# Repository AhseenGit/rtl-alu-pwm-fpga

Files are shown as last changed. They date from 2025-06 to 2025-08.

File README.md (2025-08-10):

#  RTL ALU + PWM FPGA Project

This project implements a structured digital system in Verilog RTL, targeting the Intel DE10-Standard FPGA board. The system includes a modular ALU (arithmetic, logic, shifter) and a PWM generator with three operating modes. It supports simulation, synthesis, and real hardware verification using industry-standard tools.

---

##  System Overview

- Modular ISA-driven ALU
- PWM Generator with 3 modes
- Unified control signal interface via `ALUFN[4:0]`
- Real hardware test on DE10-Standard FPGA
- RTL simulation in ModelSim
- SignalTap-based internal debugging

---

## Functional Unit Control (`ALUFN[4:3]`)

The system selects between functional blocks using the high two bits of a 5-bit `ALUFN` control signal:

| ALUFN[4:3] | Selected Unit | Function Description |
|---|---|---|
| `00` | PWM Generator | Generates variable duty-cycle PWM signal |
| `01` | Arithmetic Unit | Add, subtract, increment, negate |
| `10` | Shifter Unit | Logical/rotate left/right shift |
| `11` | Logical Unit | AND, OR, XOR, NOT, NAND |

> 🛠 Only one unit is active at a time. All units share a unified input/output interface through hardware multiplexing.

---

## Module Descriptions

### ALU Subsystem

Split into three functional RTL modules:

- `alu_arithmetic.v` – signed/unsigned math operations
- `alu_logic.v` – basic boolean logic
- `alu_shifter.v` – logical and rotational shift operations

Output is determined based on `ALUFN[4:0]` and visible via LEDs and HEX displays.

---

### PWM Generator

Implements 3 operating modes:

| Mode | Behavior Description |
|---|---|
| Mode 0 | Fixed duty cycle (manual) |
| Mode 1 | Sweep (ramp up/down duty cycle) |
| Mode 2 | Enable-controlled toggling |

> Mode is selected using lower bits of `ALUFN`.

All PWM outputs are observable on LED pins and via SignalTap.

---

## Tools & Hardware Used

| Tool | Purpose |
|---|---|
| **ModelSim** | RTL-level simulation and waveform viewing |
| **Quartus Prime**  | Synthesis, place-and-route, timing analysis |
| **SignalTap II** | Internal FPGA logic probing (live debugging) |
| **DE10-Standard**  | Target hardware for real FPGA deployment |

*Timing reports were generated automatically by Quartus. No manual slack/path optimizations were applied in this phase.*

---

## Simulation & Test Instructions

### Simulation (ModelSim)

1. Open ModelSim
2. Compile testbenches and RTL modules:
   ```bash
   vsim work.top_tb
  
## Team 
Ahseen & Aram

## contact
Feel free to reach out:
Azazmehhus@gmail.com

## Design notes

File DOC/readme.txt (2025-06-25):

#Lab4

#System Top system (top.vhd)
Inputs:
 -Signal X and Y with n bits long.
 - control signal ALUFN with 5 bits long, where the first two bits (from the left) choose the type of operation i.e.'00' for PWM Generator, '01' for arithmetic, '10' for shifting and '11' for logic ('00' will perform nothing).
  The last 3 bits of ALUFN (ALFN[2-4]) will spcify the operation after selecting the Type of the operation.
  -ENA
  -CLK
  -RST
  - Outputs
  - 4 flags: 'C' will rise to 1 if the operation produced a carry, 'Z' will rise if the result is zero, 'N' will rise if the result is negative and 'V' will rise if there overflow.
  - Output of the operation selected by ALUFN with n bits long.
  - PWM signal

## Adder/Subtractor module (AdderSub.vhd)
Will be selected if ALUFN[0:1]='01'. and will be performing 5 operations as follows:

1.Addition X+Y if ALUFN='01000'
2.Substraction Y-X if ALUFN='01001'
3.N(X) -X when ALUFN='01010'
4.Increment Y by 1 when ALUFN='01011'
5.Decrement Y by 1 when ALUFN='01100'

## Shifter Module (Shifter.vhd)
Will be selected if ALUFN[0:1]='10'. and will be performing 2 shifting operations as follows:

1. Shift Y from the right q times by adding zeros from the right when q is the decimal value of the k first bits of X from the left. Will nbe selected if ALUFN='01000'
2. Shift Y from the left q times by adding zeros from the left when q is the decimal value of the k first bits of X from the left. Will nbe selected if ALUFN='01001'

## Logic Module (Logic.vhd)
Will be selected if ALUFN[0:1]='11'. and will be performing 7 logical operations as follows:

1. not(Y) if ALUFN='11000'
2. Y or X if ALUFN='11001'
3. Y and X if ALUFN='11010'
4. Y xor X if ALUFN='11011'
5. Y nor X if ALUFN='11011'
6. Y nand X if ALUFN='11101'
7. Y xnor X if ALUFN='11111'

## Full Adder Module (FA.vhd) 
Perform addition on two single bits inputs and produce carry when needed.  

## Timer (Timer.vhd)
A counter that counts from zero to Y periodically.

## PWM Unit (PWM.vhd)
A unit that generates a PWM signal according to the ALUFN as follows:
 1.When ALUFN="00000" as PWM mode is Set/Reset.
 2.When ALUFN="00001" as PWM mode is Reset/Set.
 3.When ALUFN="00010" as PWM mode is Toggle.

## TopIO_Interface (IO_InterfaceLAB4.vhd)
Digital system with I/O interface for the hardware test case

## Package (aux_package.vhd)
A file that reuses components that needed frequently in the development of new components.

Studunts: Ahseen & Aram
Instructor: Hanan Reboh

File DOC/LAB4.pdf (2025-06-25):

## Preparation Report LAB4

## ADVANCED CPU ARCHITECTURE AND HARDWARE

## ACCELERATORS LAB

361.1.4693

## Aram Khater 314813452

## Ahseen Alazazma 324038132

מטרת המעבדה

במעבדה זו למדנו כיצד להשתמש ביכולותיה של תוכנת Quartus , ובפרט לבצע סינתזה עבור מודלים שפיתחנו

במעבדה 1 עם תוספת של חלק סינכרוני שמייצר אות PWM בשלושה מצבים. את הסינתזה ביצענו על גבי רכיב

.DE10-Standard | כרטיס | באמצעות | Cyclone II, | מסוג | FPGA

סימולצית ModelSim

נראה סימולציה של החלק החדש שפיתחנו, נותנים ערכים קבועים ל “FFF7=”X,”FFFF=”Y ו

00010“=ALUFN כדי לראות אות PWM יציב.

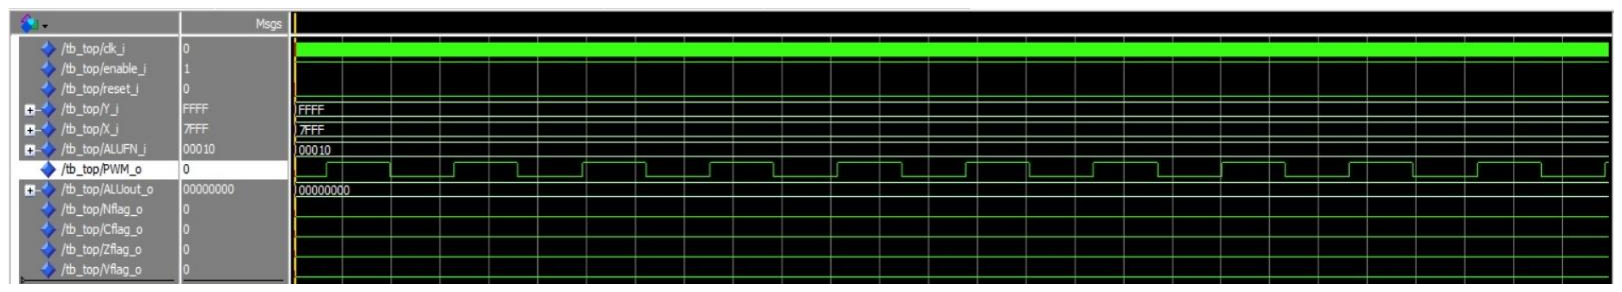
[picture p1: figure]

סימלציה עבור אות PWM במצב Toggle 1:Figure

מציאת תדר מקסימלי

על מנת למצוא את התדר המקסימלי של המערכת, יש להוסיף רגיסטרים סינכרוניים בכניסה וביציאה של ה -ALU.

לשם כך, יצרנו קובץ VHDL חדש אשר עוטף את מערכת ה ALU-ברגיסטרים, כאשר כולם מוזנים מאותו אות שעון.

את תהליך הקימפול והסינתזה ביצענו ללא השמה לפינים, כולל אות השעון, בהתאם להנחיות. לאחר השלמת הקימפול

והסינתזה, תוכנת Quartus מספקת את ערך התדר המקסימלי שבו יכולה המערכת לפעול, והתוצאה שהתקבלה היא:

עבור החלק הקומבינטורי קיבלנו:

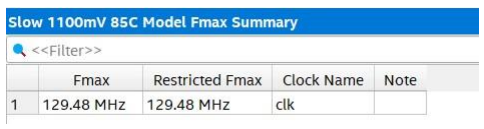
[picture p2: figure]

עבור החלק הסנכרוני קיבלנו:

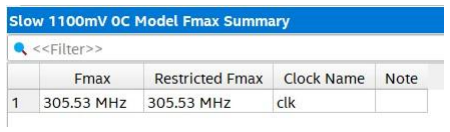
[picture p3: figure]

שיפור תדר השעון באמצעות PLL

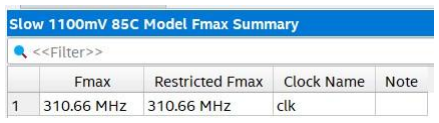
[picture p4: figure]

בנוסף, כפי שלמדנו, ניתן להעלות את תדר השעון של המערכת בעזרת רכיב חומרה מסוג PLL הקיים בכרטיס הפיתוח

שבו אנו משתמשים. רכיב זה מאפשר להכפיל או לשנות את תדר השעון הנכנס בהתאם לצרכי המערכת.

פירוט המערכת

בסעיף זה נציג סקירה כללית של המערכת שפיתחנו, וכן נפרט על תתי-המודולים המרכיבים אותה. עבור כל תת-מודול

נסביר בקצרה את אופן פעולתו, נציג את תרשים ה RTL-שלו לאחר ביצוע הסינתזה, נפרט את הלוגיקה שבה הוא

משתמש, ונאתר את הנתיב הקריטי לפעולתו. את הנתיב הקריטי נציג באמצעות כלים שמספקת תוכנת Quartus.

מערכת ה-ALU

המערכת נועדה לממש מספר מודולים שונים לביצוע פעולות לוגיות ואריתמטיות. כל מודול פועל באופן עצמאי ונפרד

מהאחרים. הבחירה באיזה מודול להשתמש מתבצעת באמצעות אות בחירה הניתן על ידי המשתמש, אשר מפעיל את

המודול הרלוונטי בהתאם לערך שנבחר.

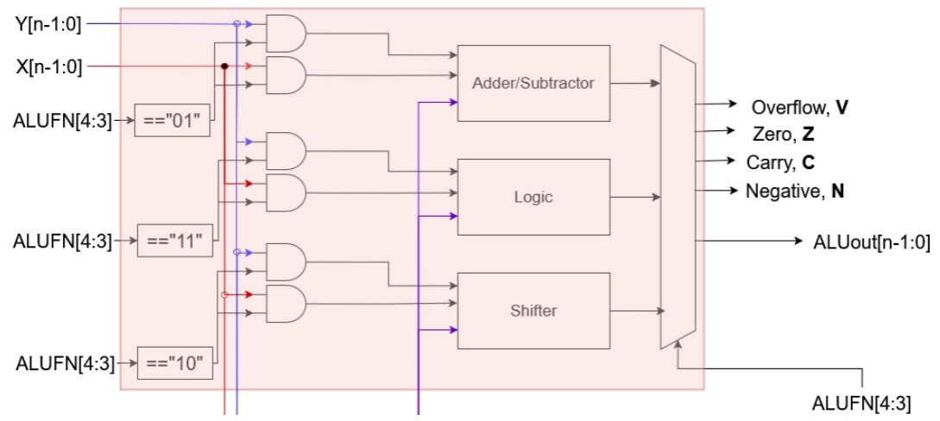
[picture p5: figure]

מודל המערכת 2: Figure

מערכת ה – ALU-מבנה וכניסות/יציאות

בסקירה הבאה נסביר על כל אחד מתתי-המודולים בנפרד. מערכת ה ALU-מקבלת שלוש כניסות עיקריות:

- אות כניסהX
- אות כניסהY
- קו בקרה ,ALUFN שבו:
- הביטים 3ו4- משמשים לבחירת המודול:
- 01 מודול AdderSub
- 10 מודול Shifter
- 11 מודול Logic
- הביטים 0,1,2משמשים כבקרת פעולה פנימית בתוך כל מודול, ומאפשרים לו לפעול במספר אופנים

שונים בהתאם לערכם.

יציאות המערכת כוללות ארבעה רכיבים:

- שלושה דגלים:
o) – Negative (N מסמן אם התוצאה שלילית
o) – Zero (Z מסמן אם התוצאה היא אפס
o) – Carry (C מסמן אם התרחשה נשיאה(Carry(
o) Overflow(V מסמן אם התרחשה גלישה אריתמטית (Overflow (בפעולות חיבור/חיסור
- מוצא – ALUout מייצג את התוצאה של המודול שנבחר לפעולה, בהתאם לערך שבקו הבקרה ALUFN .

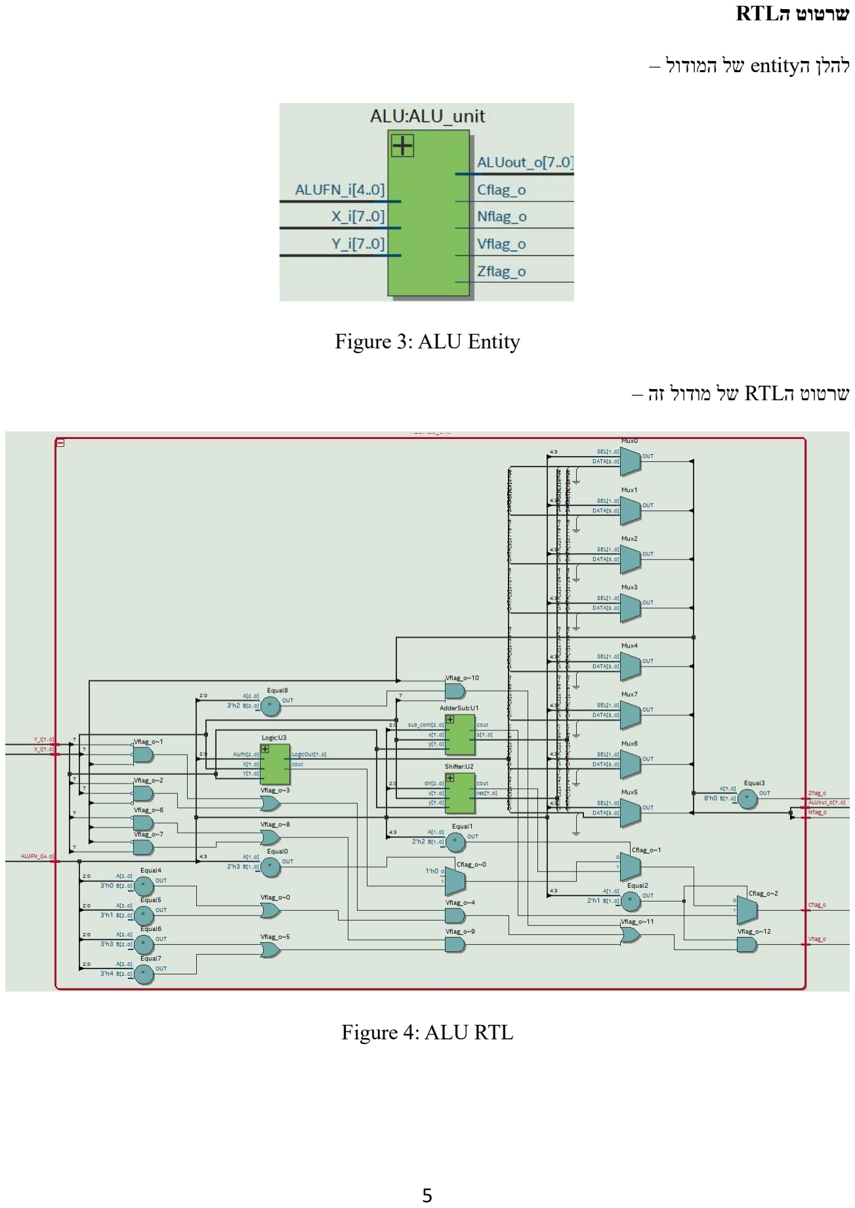
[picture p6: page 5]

שרטוט הRTL

להלן הentity של המודול –

Figure 3: ALU Entity

שרטוט הRTL של מודול זה –

Figure 4: ALU RTL

שימוש בלוגיקה

כידוע, אנו מפתחים קוד לוגי המבוסס על רכיבים לוגיים הניתנים לקונפיגורציה בהתאם לקוד שנכתב – תהליך

שמבוצע כחלק מתהליך הסינתזה. בניתוח זה נציג את הלוגיקה שנעשה בה שימוש עבור כל אחד מהמודולים, בהתאם

לדרישות, ונפרט כיצד ממומשת כל פעולה ברמת השערים או המבנה הפנימי של המודול.

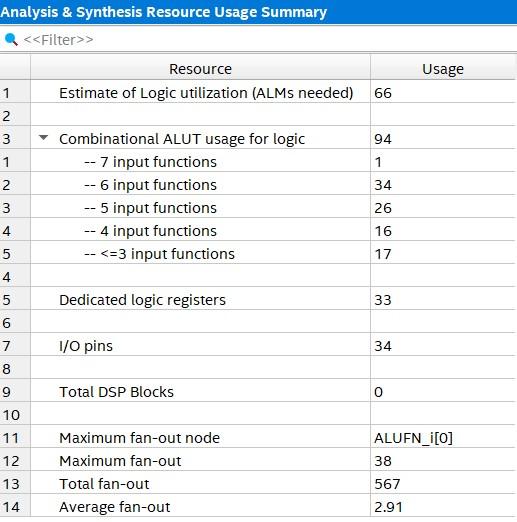
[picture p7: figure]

Figure 5: System Logic Usage

נתיב קריטי

הנתיב הקריטי הוא מרכיב מרכזי להבנת זרימת המידע במערכת, והוא קובע את זמן ההתייצבות המינימלי הדרוש לפני

שניתן לעבד קלט חדש. מאחר שלכל רכיב לוגי קיימת השהיה – גם כאשר הם פועלים במקביל – יש להביא בחשבון

את זמן ההשהיה הכולל במערכת. לכן, איתור הנתיב הקריטי מאפשר לנו להעריך את ביצועי המערכת ולקבוע את

התדר המקסימלי האפשרי לפעולה.

להלן מציאת הנתיב הקריטי עבור מודול זה, כפי שנעשה באמצעות כלי הניתוח של תוכנת Quartus :

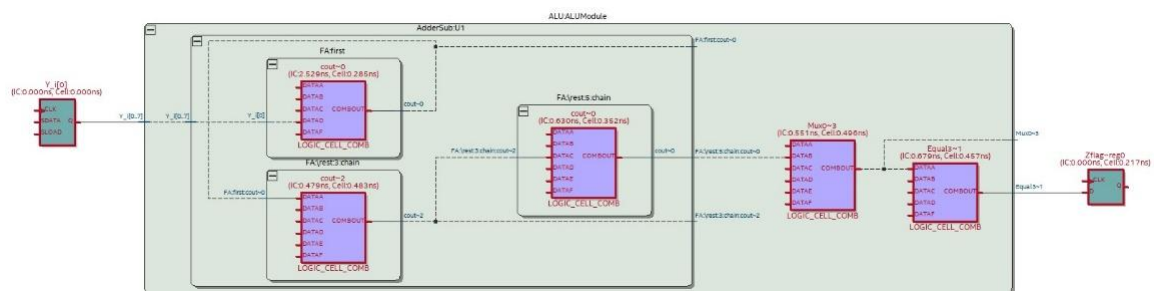
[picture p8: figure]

Figure 6: ALU Critical Path

מודול AdderSub

סקירת פעולת המודול

מודול זה מבצע, בהתאם לקו הבקרה ,ALUFNאחת מתוך מספר פעולות אריתמטיות על שני סיגנלים באורך זהה –

Xו .Y-הפעולות כוללות:

- חיבור (Addition (של X ו Y-באמצעות שרשרת חוסרי חיבור(FA – Adders Full(
- חיסור (Subtraction (באמצעות הוספת המשלים של X
- היפוך ביטים – (NEG (הפעלת היפוך ביט- ביט
- הוספה של 1 ל Y) –Increment (ביצוע 1 + Y
- הפחתה של 1 מ Y) –Decrement (ביצוע 1 – Y
- החלפת סדר בתים ב Y) –Swap (היפוך סדר הבתים של Y

הבחירה בפעולה המתבצעת נעשית לפי הביטים ,[2:0]ALUFN כאשר כל ערך תואם לפעולה שונה.

שרטוט הRTL

להלן הentity של המודול –

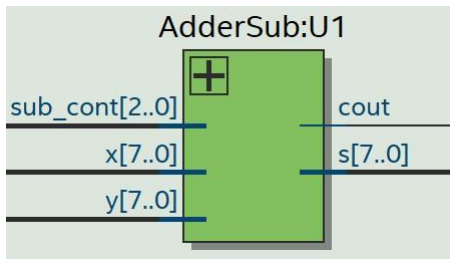
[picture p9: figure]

Figure 7: AdderSub Entity

שרטוט הRTL של מודול זה –

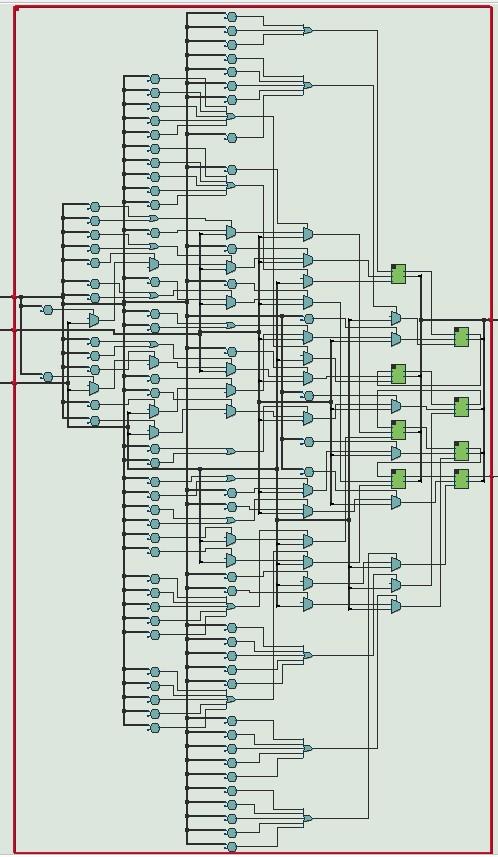
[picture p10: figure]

Figure 8: AdderSub RTL

מודול – Shifter

סקירת פעולת המודול

מודול זה מבצע פעולת הזזה (Shift (על בסיס מבנה ,Shifter Barrel בהתאם לערכי קו הבקרה .ALUFN

כאשר הביטים [2:0]ALUFNהם:

- – '000' מתבצעת הזזה שמאלה
- – '001' מתבצעת הזזה ימינה

למימוש המודול, עברנו על כל אחת מ־ k השכבות כאשר n 2log=k ובכל שכבה מתבצעת הזזה מותנית. עבור כל

שכבה:

- אם הביט המתאים בשכבת הבקרה(ממוצא ה X(הוא 0 – לא מתבצעת הזזה, והמוצא של השכבה זהה

לכניסתה

- אחרת נבצע הזזה בהתאם לשכבה

בנוסף, לצורך חישוב ה Carry-(סיבית שנדחפה החוצה במהלך ההזזה(, יצרנו סיגנל ייעודי אשר שומר את ערכי ה-

Carry בכל שלב, וממנו אנו מחזירים את הסיבית המתאימה )לרוב האחרונה( כמוצא carry של המודול.

שרטוט הRTL

להלן הentity של המודול –

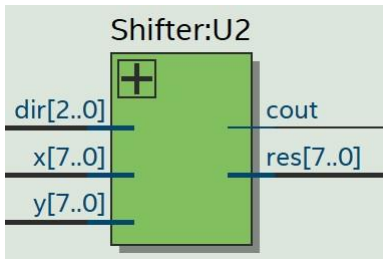
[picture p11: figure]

Figure 9: Shifter Entity

שרטוט הRTL של מודול זה –

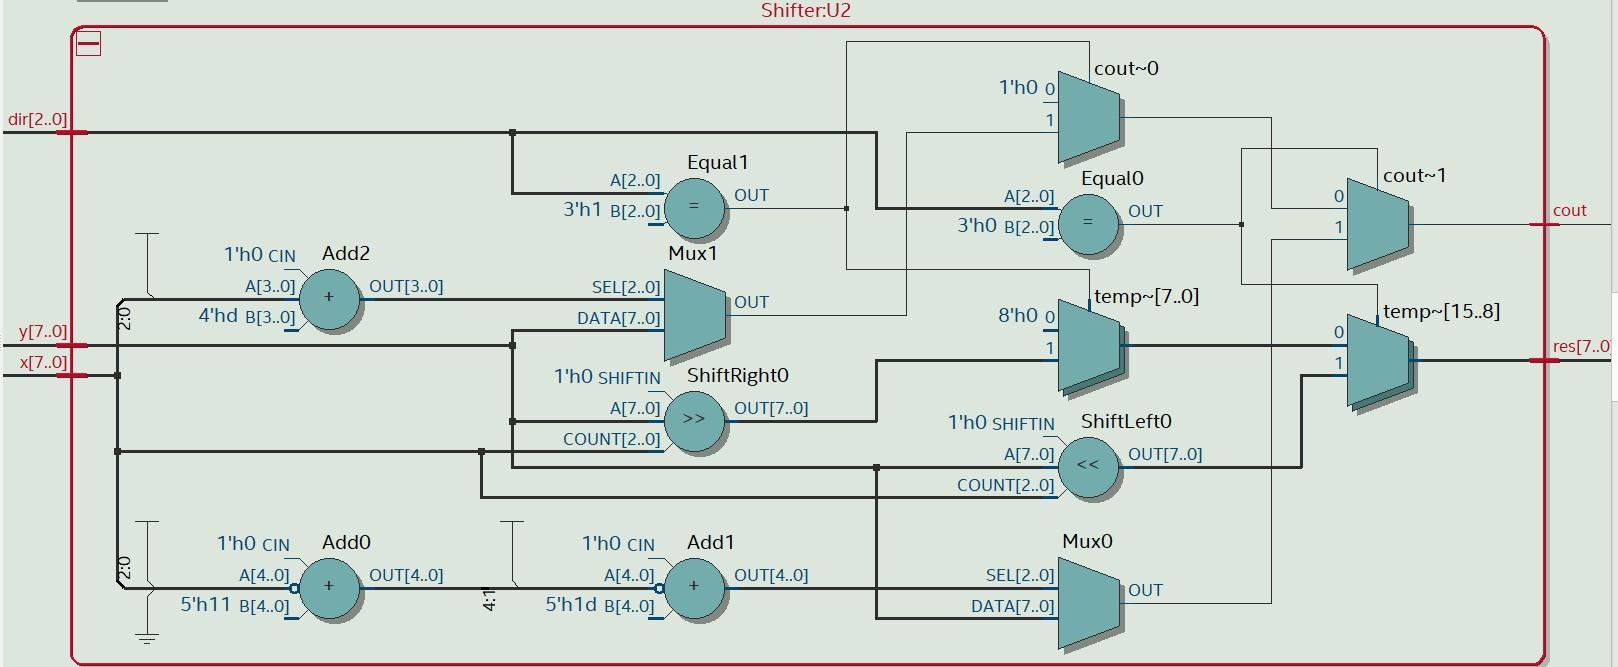
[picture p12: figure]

Figure 10: Shifter RTL

מודול – Logic

סקירת פעולת המודול

מודול זה מבצע פעולות לוגיות שונות בין הסיגנלים Xו ,Y-בהתאם לערכי קו הבקרה ALUFN.

הבחירה בפעולה המתאימה נעשית לפי ערכי הביטים ,[2:0]ALUFNבהתאם להגדרות שניתנו ב ISA-המצורפת.

מבנה המודול מאפשר הרחבה עתידית לפעולות לוגיות נוספות במידת הצורך, תוך שמירה על פשטות המימוש

והיעילות בזמן סינתזה.

שרטוט הRTL

להלן הentity של המודול –

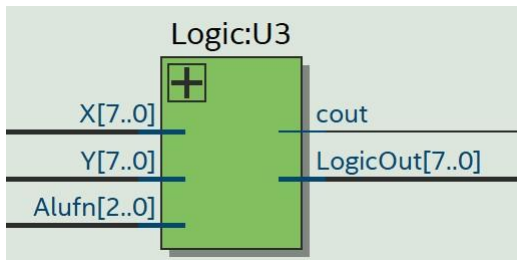
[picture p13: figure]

Figure 11: Logic Entity

שרטוט הRTL של מודול זה –

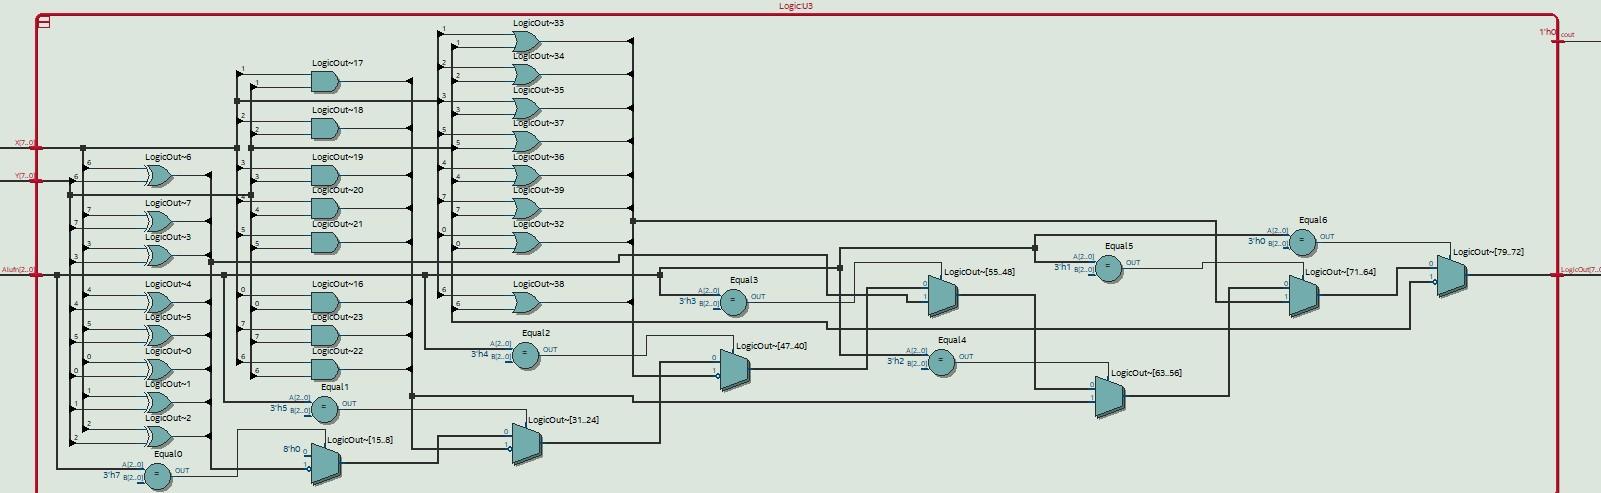
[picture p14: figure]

Figure 12: Logic RTL

מערכת ה PWM

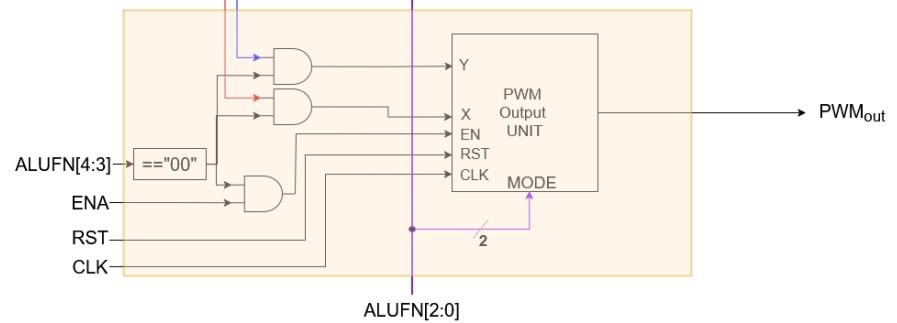
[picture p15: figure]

Figure 13: PWM Module

המערכת תקבל 6 כניסות ותייצר אות PWM בשלושה מצבים:

- אות כניסה X.
- אות כניסה Y.
- שעון CLK.
- קו ENA שעוצר או מפעיל את המערכת.
- קו RST שמאפס את המערכת
- קו בקרה ALUFN כאשר ביטים 0,1 קובעים את המודול הנבחר כך ש-
Set/Reset | במצב | PWM | נבחר | " 00 " | -
Reset/Set | במצב | PWM | נבחר | " 01 " | -
- "10" נבחר PWM במצב Toggle

שרטוט הRTL

להלן הentity של המודול –

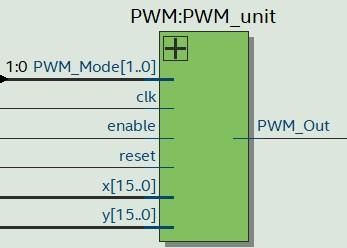
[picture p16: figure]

Figure 14: PWM Entity

שרטוט הRTL של מודול זה –

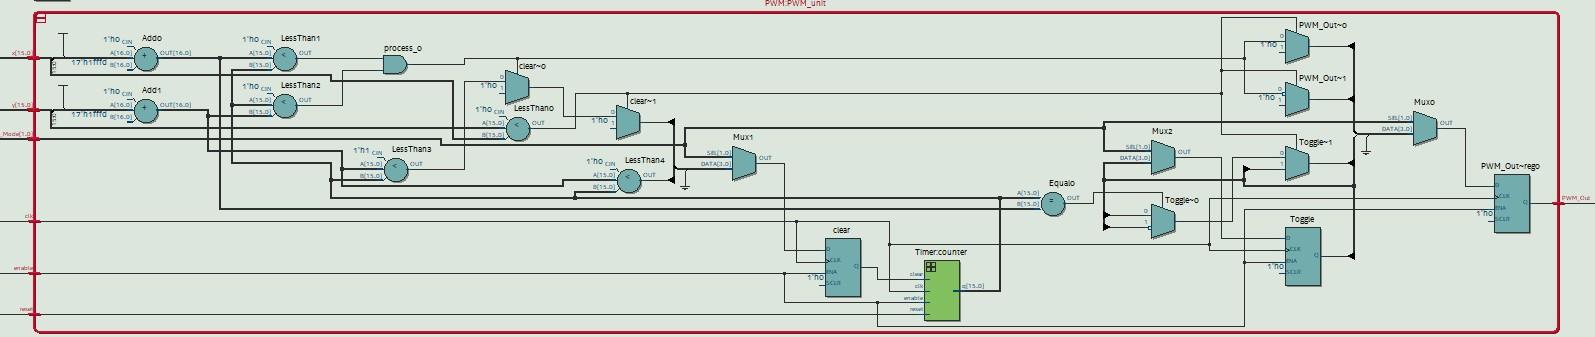
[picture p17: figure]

Figure 15: PWM RTL

בשימוש בלוגיקה

כידוע אנחנו מפתחים קוד לוגי אשר משתמש באלמנטים לוגים שניתן לקנפג אותם בהתאם לקוד, דבר

שנעשה כחלק מתהליך הסינתזה. בניתוח זה נציג את הלוגיה עבור כל מודול כנדרש –

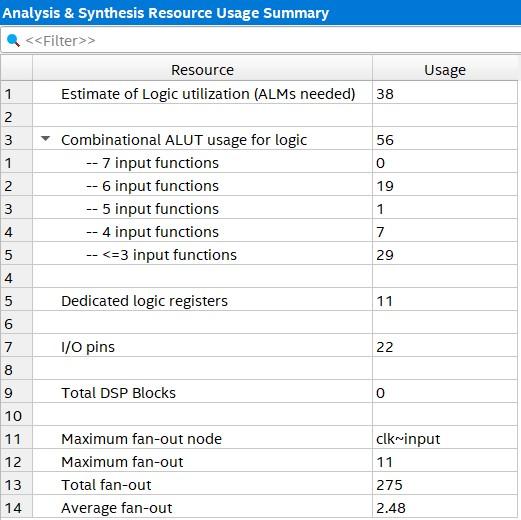
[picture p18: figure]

Figure 16: System Logic Usage

נתיב קריטי

הנתיב הקריטי חשוב ביותר להבנת זרימת המידע במערכת. מפני שלרכיבים יש השהייה גם אם הם

מקביליים אזי עלינו לקחת בחשבון את אורך הזמן שלוקח למערכת להתייצב לפני הכנסת כניסה חדשה.

להלן מציאת הנתיב הקריטי במודול זה –

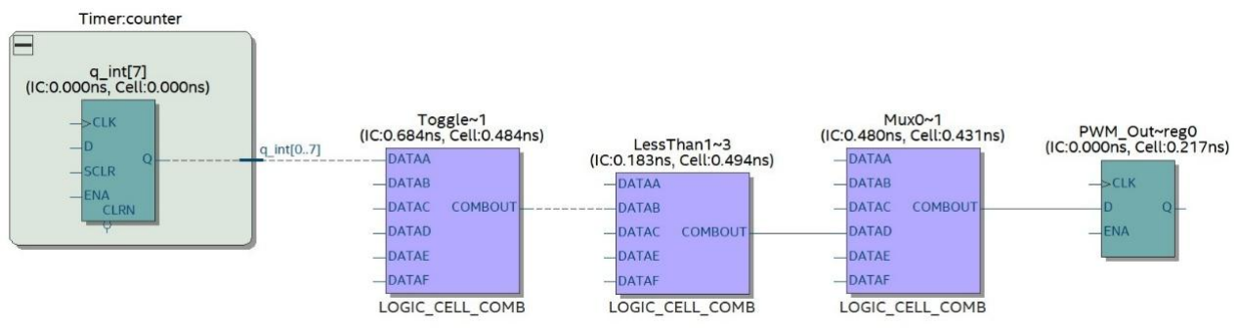
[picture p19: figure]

Figure 17: PWM Unit Critical Path

מודול – Timer

מודול זה מבצע מנייה כלפי מעלה עד שיגיע לערך של Y ומתחיל שוב מנייה מאפס.

שרטוט הRTL

להלן הentity של המודול –

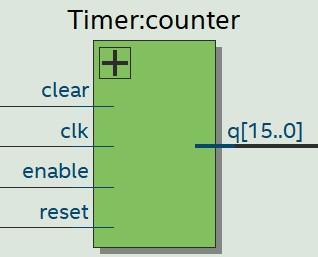
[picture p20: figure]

Figure 18: Timer Entity

שרטוט הRTL של מודול זה –

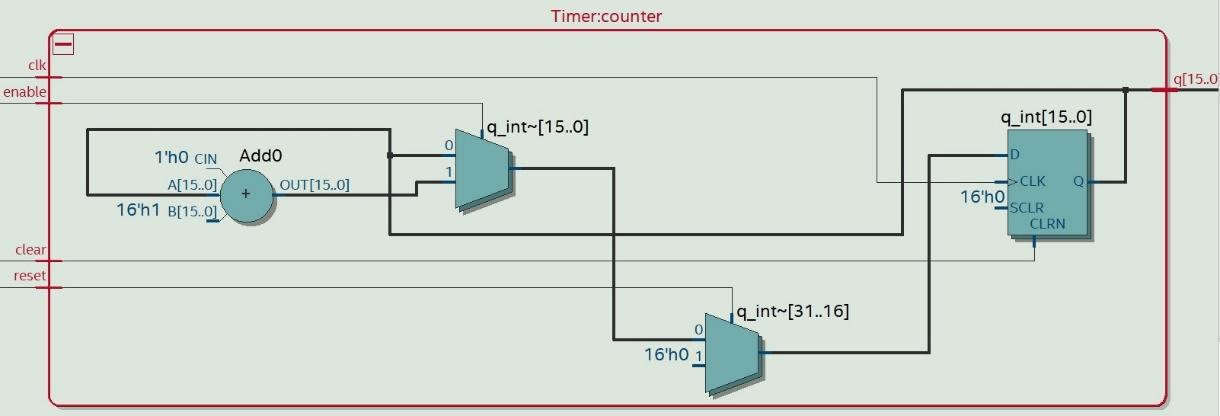
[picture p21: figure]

Figure 19: Timer RTL

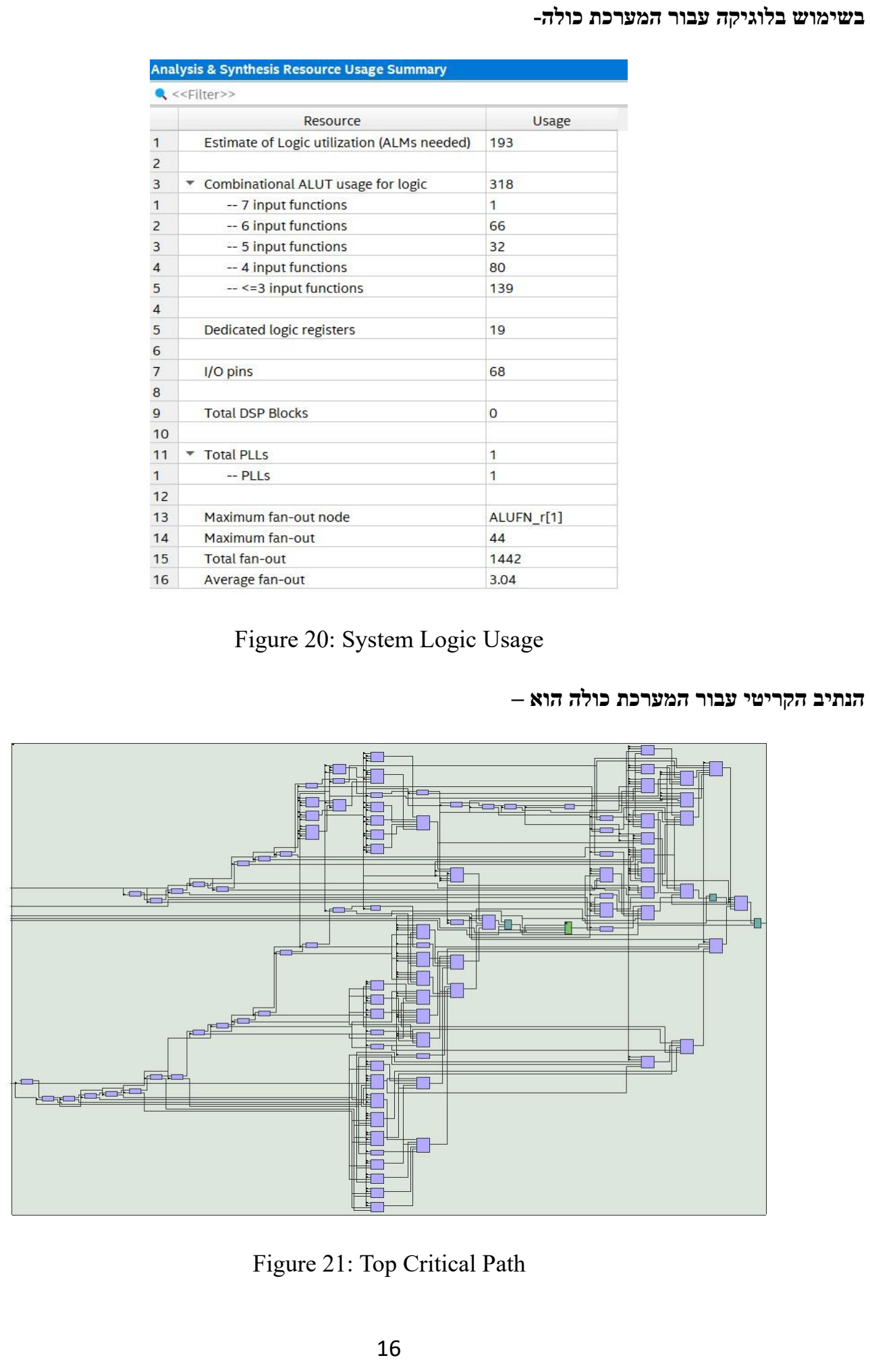
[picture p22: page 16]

בשימוש בלוגיקה עבור המערכת כולה-

Figure 20: System Logic Usage

הנתיב הקריטי עבור המערכת כולה הוא –

Figure 21: Top Critical Path

Signal Tap

לצורך ביצוע ווריפיקציה של החומרה שפיתחנו, השתמשנו בכלי Tap Signal של תוכנת Quartus. הכלי מאפשר

לתפוס את מצבי הסיגנלים ברכיב בזמן אמת, ולנתח את התנהגות המערכת במהלך הפעולה.

במסגרת הניסוי, הגדרנו את הסיגנלים אותם נרצה ללכוד – ובפרט את סיגנלי Keys , נלכוד אותם בעת עליית המתח

(Edge Rising(, כלומר כאשר נשחרר את המפתח. במהלך הריצה, אנו מדפיסים ומנתחים את ערכי הכניסות

והמוצאים של המערכת בזמן אמת, לצורך בדיקת תקינות וביצועים.

פעולת Shifter –

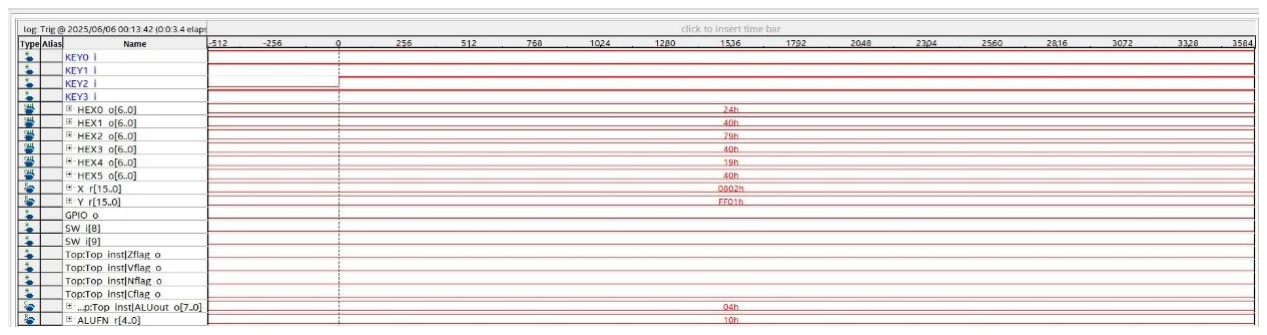
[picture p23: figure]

Figure 22: SHL Operation

בפעולה זו, נרצה לבצע הזזה שמאלה לא ציקלית על ידי ה- 10000 = Opcode של הווקטור Y כמות

הפעמים של ]0..2[X. כאן ההזזות היא 2 והערך של Y הוא 00000001 ולכן קיבלנ ו ב ALUout את הערך h04 שזה

.00000100

פעולת חיבור –

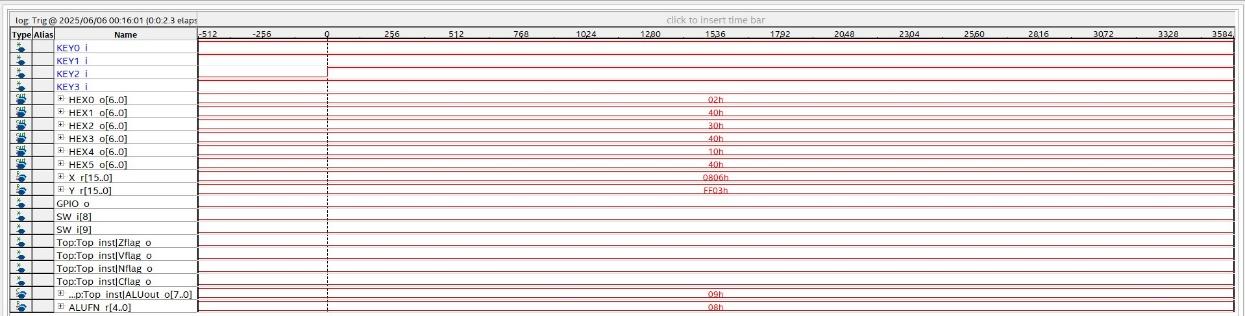
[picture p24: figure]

Figure 23: ADD Operation

בפעולה זו נרצה לבצע חיבור בין X ו Y ע"י ה- 01000=Opcode. ניתן לראות שהערכים של XוY הם 6ו3 ולכן

קיבלנו ב ALUout את הערך h.09

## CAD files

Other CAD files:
Quartus/Arith.stp
Quartus/shl.stp
